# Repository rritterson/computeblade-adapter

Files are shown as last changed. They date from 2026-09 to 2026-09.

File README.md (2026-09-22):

# Compute Blade ↔ DDA GPS/RTC adapter — parallel-DDA revision

This repository contains a passive two-connector KiCad adapter that remaps the Dark Dragons Astronomy GPS PPS signal while keeping the unmodified DDA PCB parallel to the Compute Blade PCB. Physical connector pin numbers are authoritative; GPIO names are descriptions and are never interpreted as BCM pin numbers.

The project targets **KiCad 10.0.5** through the pinned `kicad/kicad:10.0.5-full` CI image.

> Passing connectivity, ERC, DRC, CAD collision, and clearance checks is required but does not make this design fabrication-ready. Connector seating forces and final BladeRunner fit still require a physical prototype.

## Approved architecture

- **J1:** Samtec `HLE-105-02-L-DV-PE-BE`, 2×5, 2.54 mm, bottom-entry/pass-through receptacle.
- **J2:** Samtec `MTLW-106-05-G-D-140`, 2×6, 2.54 mm, conventionally mounted vertical male header; its manufacturer-designated gold-plated mating post points toward the DDA.
- Adapter: 2-layer 1.0 mm FR-4, nominal 1 oz / 35 µm copper.
- Compute Blade, adapter, and DDA PCB planes are all XY.
- DDA socket/battery face points inward (−Z), toward the adapter and Compute Blade.
- DDA GNSS face points outward (+Z), toward the neighboring blade.
- The DDA remains electrically and mechanically unmodified.

The exact footprints are project-local in `pcb/Adapter.pretty/`. They use the manufacturer 2.54 mm patterns, explicit fab outlines, courtyards, 1.0 mm drills, and 1.8 mm pads. That gives a nominal 0.40 mm annular ring. The 1.0 mm board provides a conventional, stiff interposer, but the selected fabricator must still confirm 1.0 mm FR-4, 1.0 mm plated drills, and its finished-hole/annular-ring rules before ordering.

The generated connector STEP models are manufacturer-dimensioned approximations because exact configured Samtec CAD is not available to deterministic unauthenticated CI. They are not substitutes for a first-article fit test.

## Coordinate and orientation contract

```text
X = Compute Blade long axis
Y = Compute Blade width
Z = outward normal from the Compute Blade PCB

Compute Blade PCB plane = XY
adapter PCB plane       = XY
DDA PCB plane           = XY
DDA PCB normal          = +Z
DDA socket mating axis  = -Z toward adapter
J2 mating posts         = +Z
J2 six-position axis    = +X
J2 row 1 → row 2        = -Y
```

The shared DDA transform is the identity basis:

```text
[[1, 0, 0],
 [0, 1, 0],
 [0, 0, 1]]
```

`scripts/design_config.py` is the sole parameter source used by the PCB generator, geometry validator, STEP generator, SVG generator, and PNG renderer. Unit tests hard-fail if the DDA becomes upright, the GNSS face points inward, the mating direction reverses, or J2’s columns/rows change axes.

## Exact physical-pin mapping

| Physical pin | J1 Compute Blade | J2 DDA | Adapter net |
|---:|---|---|---|
| 1 | 3V3 | 3V3 | `3V3` |
| 2 | 5V | unused by DDA | `5V_PIN2` |
| 3 | GPIO2 / SDA | SDA | `SDA_GPIO2` |
| 4 | 5V | unused by DDA | `5V_PIN4` |
| 5 | GPIO3 / SCL | SCL | `SCL_GPIO3` |
| 6 | GND | GND | `GND_PIN6` |
| 7 | GPIO4 / PPS_IN | unused DDA position | `PPS_GPIO4` |
| 8 | GPIO14 / UART_TX | GPS_RX | `UART_TX_TO_GPS_RX` |
| 9 | GND | unused by DDA | `GND_PIN9` |
| 10 | GPIO15 / UART_RX | GPS_TX | `UART_RX_FROM_GPS_TX` |
| 11 | — | RTC_INT | **NC** |
| 12 | — | GPS_PPS | `PPS_GPIO4` |

Pins J1.1–J1.10 map one-for-one to J2.1–J2.10. J2.12 additionally joins J1.7/J2.7, so GPS PPS reaches Compute Blade physical pin 7 / GPIO4. J2.11 remains explicitly unconnected. Duplicate rails remain separate: `5V_PIN2`, `5V_PIN4`, `GND_PIN6`, and `GND_PIN9` are not merged by the adapter.

## Dimension provenance and stack calculation

Physically measured Compute Blade dimensions:

- PCB surface to header-plastic top: 2.500 mm.
- PCB surface to pin tip: 9.000 mm.
- Exposed post: 6.500 mm.

Manufacturer HLE requirements:

- Bottom-entry minimum reach: 2.590 mm plus host PCB thickness and the intentional seating gap.
- `J1_SEATING_GAP_MM = 0.350` is the single authoritative gap between the Compute Blade header-plastic top and adapter/J1 seating plane.
- With a 1.000 mm adapter and the 0.350 mm gap, required reach is 3.940 mm.
- The measured 6.500 mm post exceeds this requirement by 2.560 mm.
- `-PE-BE` is open/pass-through, so excess post does not bottom in a closed socket.
- Adapter underside is therefore 2.850 mm above the Compute Blade PCB. The 0.350 mm separation is an intentional assembly datum, not an assumed connector-body height; assembly should use a 0.35 mm seating gauge/fixture and verify the resulting separation on the first article.

The same exact connector Z-chain was evaluated at all requested gaps:

| Seating gap | Adapter underside | J1 required reach | J1 surplus | J2 tail clearance | Outward stack | Physical clearance | Margin after reserve |
|---:|---:|---:|---:|---:|---:|---:|---:|
| 0.300 mm | 2.800 mm | 3.890 mm | 2.610 mm | 0.366 mm | 17.776 mm | 2.1557 mm | 1.1557 mm |
| **0.350 mm** | **2.850 mm** | **3.940 mm** | **2.560 mm** | **0.416 mm** | **17.826 mm** | **2.1057 mm** | **1.1057 mm** |
| 0.400 mm | 2.900 mm | 3.990 mm | 2.510 mm | 0.466 mm | 17.876 mm | 2.0557 mm | 1.0557 mm |

The preferred 0.350 mm value passes every hard gate while retaining more BladeRunner margin than 0.400 mm and giving more tail clearance than 0.300 mm.

Manufacturer MTLW geometry:

```text
OAL                                      8.510 mm
insulator                                1.520 mm
designated -140 mating post              3.556 mm
solder tail                              3.434 mm
DDA insertion                            3.400 mm
free post after insertion                0.156 mm
lower solder-tail tip above blade PCB    0.416 mm
```

`MTLW-106-05-G-D-140` uses the normal manufacturer orientation: the `-140` post is the DDA mating end and receives the specified 10 µin gold plating; the opposite 3.434 mm segment is the solder tail. Samtec lists this exact configuration in its Reserve program. See the [exact Samtec product page](https://www.samtec.com/products/mtlw-106-05-g-d-140) and [official MTLW series print](https://suddendocs.samtec.com/catalog_english/mtlw_th.pdf).

Measured DDA geometry:

- PCB: 16.5 × 22.5 × **1.6 mm**.
- Socket mating face to socket-side PCB surface: 8.3 mm.
- Socket-side PCB surface to GNSS top: **4.0 mm total**.
- GNSS projection beyond the opposite PCB surface: 2.4 mm.
- Battery/RTC inward local envelope: 4.75 mm.

The 4.0 mm value already includes the 1.6 mm PCB. It must not be calculated as `1.6 + 4.0`.

```text
adapter underside                                  2.850 mm
+ adapter PCB                                      1.000 mm
+ MTLW insulator                                   1.520 mm
+ unused designated post after insertion           0.156 mm
= DDA socket mating face                           5.526 mm
+ mating face to socket-side PCB surface           8.300 mm
+ socket-side surface to GNSS top                  4.000 mm
= total outward stack                             17.826 mm
```

## Placement and BladeRunner clearance

The official Compute Blade STEP anchors J3 at `(133.075077, 18.325065, 0.0)` mm. The selected complete DDA projection is:

```text
X = 160.000 .. 176.500 mm
Y =  19.500 ..  42.000 mm
```

The validator extracts the official PCB solid bounds from the STEP and requires the full DDA PCB, socket, GNSS envelope, and inward battery envelope to remain inside its XY footprint with a 0.5 mm configured margin.

BladeRunner clearance uses the physical slit-edge result, not slit centerline pitch:

```text
physical per-blade clearance       19.9317 mm
safety reserve                      1.0000 mm
design maximum                     18.9317 mm
approved outward stack             17.8260 mm
physical nominal clearance          2.1057 mm
margin after 1.0 mm reserve         1.1057 mm
```

CI authenticates the pinned official `half body.stl`, rechecks its mesh encoding, triangle count, hash, and outer bounds, and applies the previously slit-edge-derived 19.9317 mm physical clearance. It does not substitute the obsolete `(-1.5, 45.0)` clearance box or the former 36 mm total-depth rule.

## Official CAD and mechanical validation

`scripts/fetch_reference_cad.py` authenticates upstream CAD at immutable Compute Blade commit `9c7e472f4fb5c74401d17cdc7a766254d78a32c6`:

- `models/blade/v1.0-mk4/v1.0_mk4_DEV.step`
- `models/bladerunner/19-inch/half body.stl`
- `models/bladerunner/19-inch/left bracket.stl`
- `models/bladerunner/19-inch/right bracket.stl`

Pure-Python validation checks the shared transforms, pin-1 mapping, designated J2 mating end, connector reach, 3.40 mm insertion, the 0.30 mm minimum tail clearance, DDA XY keep-in, 17.826 mm stack, 2.00 mm minimum physical clearance, and 1.00 mm minimum post-reserve margin. The CadQuery assembly stage additionally intersects the DDA, J2, and adapter-outside-J1 region against the exact official Compute Blade B-Rep and fails on material overlap.

The confirmed DDA pin-1 orientation remains:

- readable GNSS/component side: bottom-left;
- underside/socket-hole view: bottom-right.

This is encoded independently of electrical net names.

## Inspecting the assembly

`scripts/generate_assembly_model.py` produces:

- `mechanical/generated/full_assembly.step`
- `mechanical/generated/full_assembly_lightweight.step`
- `mechanical/generated/full_assembly_with_bladerunner.step`
- standalone J1/J2 approximation STEP models
- top, side, end, isometric, J1-closeup, and J2/DDA-closeup PNGs

The full assembly imports the exact official Compute Blade B-Rep. The BladeRunner-context assembly adds the validated 18.9317 mm design plane and 19.9317 mm physical-clearance plane. All placement uses the same boxes and transforms as `validate_geometry.py`; there is no separate visual-only placement.

Open the STEP files in FreeCAD. From a successful GitHub Actions run, download the `compute-blade-dda-adapter-reports` artifact for the STEP files, fixed renders, manifests, ERC/DRC reports, and board views. The visual model is an inspection aid and does not replace a physical prototype.

## Regeneration and CI

```sh
python3 scripts/fetch_reference_cad.py
python3 scripts/generate_schematic.py
python3 scripts/generate_or_update_pcb.py
python3 scripts/generate_mechanical_model.py
python3 scripts/verify_connectivity.py
python3 -m unittest discover -s scripts -p 'test_*.py' -v
python3 scripts/validate_geometry.py
python3 -m pip install --requirement requirements-assembly.txt
python3 scripts/generate_assembly_model.py
```

GitHub Actions repeats deterministic generation, connectivity verification, unit tests, geometry validation, STEP round-trip checks, blank-render checks, KiCad ERC/DRC, Gerber export, and Excellon drill export. Download `compute-blade-dda-adapter-manufacturing` for `compute-blade-dda-adapter-gerbers.zip`; the BOM is included in `compute-blade-dda-adapter-reports`.

## Prototype-only risks

- First-article confirmation that the specified 0.350 mm HLE seating gap can be set and retained using the assembly gauge/fixture, plus practical soldering on 1.0 mm FR-4.
- Production-tolerance and solder-fillet confirmation for the nominal 0.416 mm gap between the J2 tail tips and Compute Blade PCB plane.
- Physical connector insertion and extraction forces.
- Residual differences between simplified connector bodies and production parts.
- Final assembled fit in a real 19-inch BladeRunner, including manufacturing and seating tolerances.
- First-article confirmation before ordering multiple boards.

The project must not be described as fabrication-ready until those physical checks are closed.

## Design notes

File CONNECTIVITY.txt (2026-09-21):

Compute Blade to DDA GPS/RTC adapter connectivity
Physical header pin numbers only

Pin     Net
------- ---------------------------
J1.1   3V3
J1.2   5V_PIN2
J1.3   SDA_GPIO2
J1.4   5V_PIN4
J1.5   SCL_GPIO3
J1.6   GND_PIN6
J1.7   PPS_GPIO4
J1.8   UART_TX_TO_GPS_RX
J1.9   GND_PIN9
J1.10  UART_RX_FROM_GPS_TX
J2.1   3V3
J2.2   5V_PIN2
J2.3   SDA_GPIO2
J2.4   5V_PIN4
J2.5   SCL_GPIO3
J2.6   GND_PIN6
J2.7   PPS_GPIO4
J2.8   UART_TX_TO_GPS_RX
J2.9   GND_PIN9
J2.10  UART_RX_FROM_GPS_TX
J2.11  NC
J2.12  PPS_GPIO4

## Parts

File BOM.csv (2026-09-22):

Reference | Quantity | Manufacturer | Manufacturer Part Number | Description | Mounting
J1 | 1 | Samtec | HLE-105-02-L-DV-PE-BE | 2x5 2.54 mm bottom-entry pass-through receptacle | Top / through-hole
J2 | 1 | Samtec | MTLW-106-05-G-D-140 | 2x6 2.54 mm variable-post header in conventional mating orientation | Top / through-hole

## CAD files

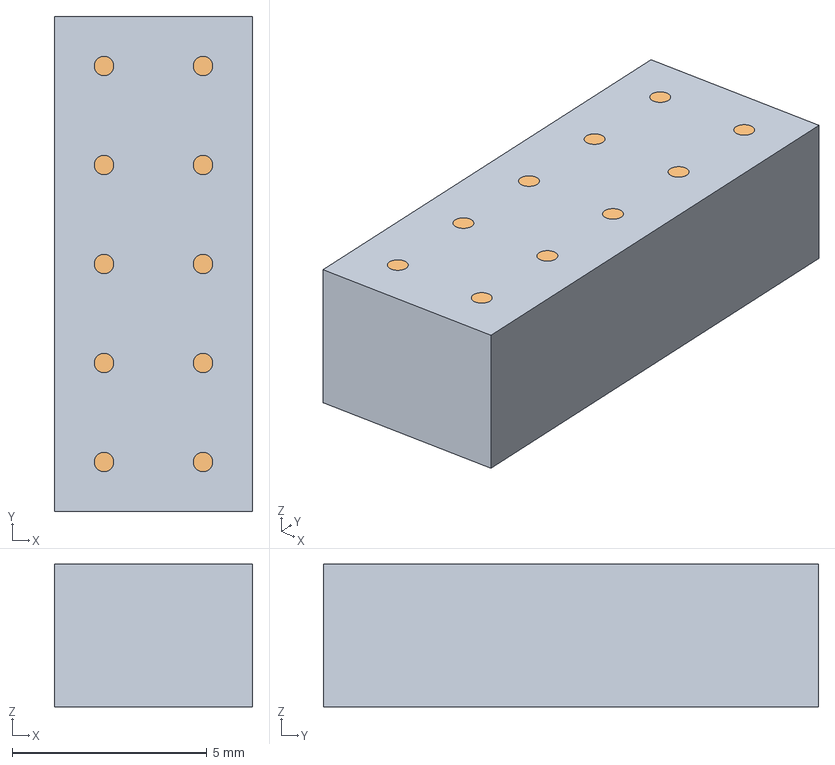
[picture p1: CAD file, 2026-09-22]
mechanical/generated/j1_hle_105_02_l_dv_pe_be.step
5.08 x 12.7 x 3.66 mm

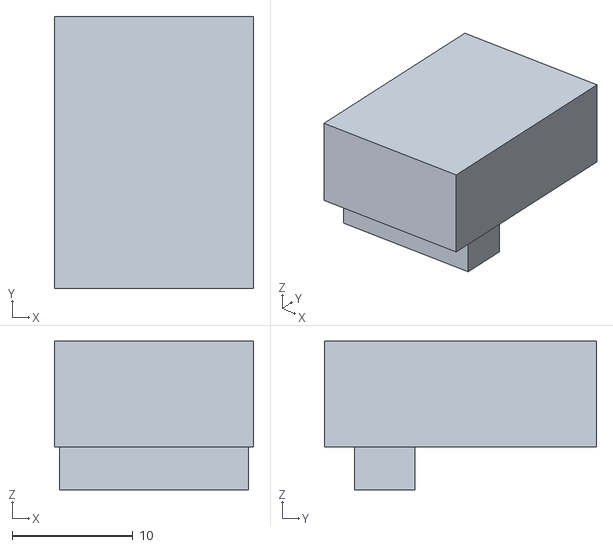
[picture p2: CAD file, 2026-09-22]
mechanical/generated/dda_simple_default.stl
16.5 x 22.5 x 12.3

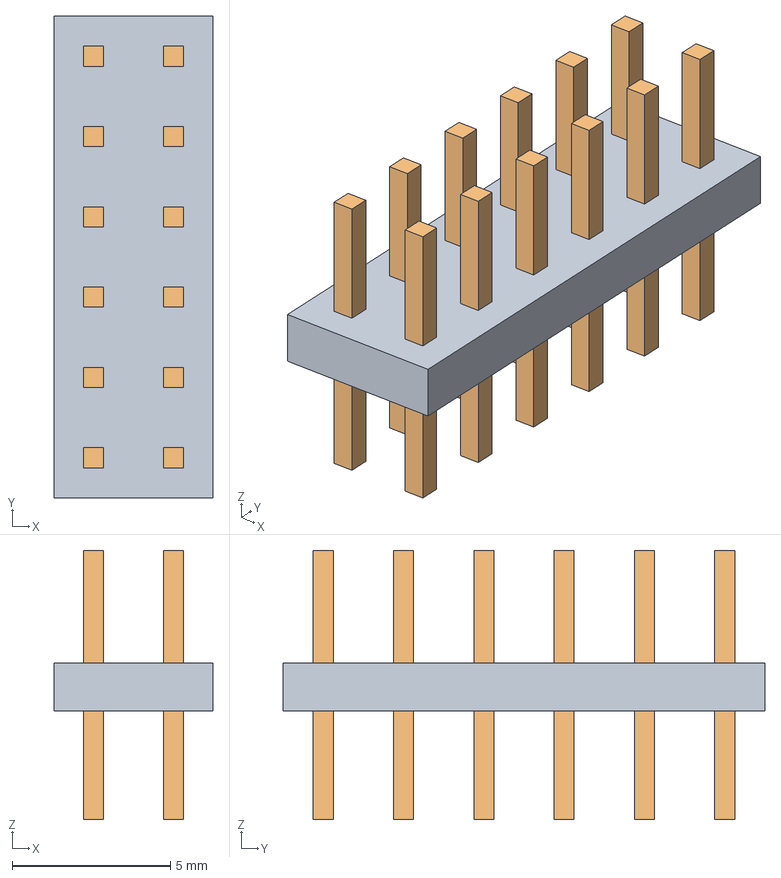
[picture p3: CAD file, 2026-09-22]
mechanical/generated/j2_mtlw_106_05_g_d_140.step
5.03 x 15.2 x 8.51 mm

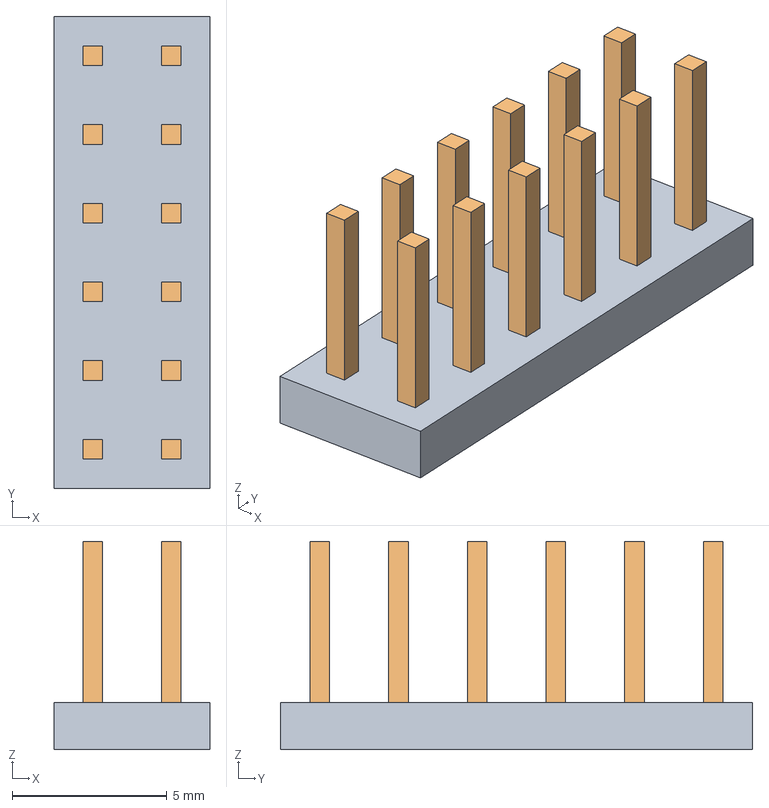
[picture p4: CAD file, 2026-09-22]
mechanical/generated/j2_mtlw_106_06_g_d_035_reverse.step
5.03 x 15.2 x 6.73 mm

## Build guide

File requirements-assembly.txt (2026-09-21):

# Pinned CAD and headless-rendering toolchain used by pcb-ci.yml.
cadquery==2.5.2
cadquery-ocp==7.7.2
numpy==2.0.2
Pillow==11.3.0

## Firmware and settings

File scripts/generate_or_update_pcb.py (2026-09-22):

#!/usr/bin/env python3
"""Deterministically generate the routed two-connector KiCad PCB."""

from __future__ import annotations

import uuid
import math
import heapq
from pathlib import Path

from design_config import (
    BOARD_THICKNESS_MM,
    BOARD_BOUNDS_RELATIVE_J1_MM,
    ROUTING_BOUNDS_RELATIVE_J1_MM,
    J1_FOOTPRINT,
    J1_MODEL,
    J1_ORIGIN_MM,
    J1_CANDIDATE_PART,
    J2_FOOTPRINT,
    J2_FOOTPRINT_ROTATION_DEG,
    J2_MODEL,
    J2_ORIGIN_MM,
    J2_CANDIDATE_PART,
    J2_CENTERLINE_OFFSET_MM,
    PITCH_MM,
    POWER_TRACE_WIDTH_MM,
    SIGNAL_TRACE_WIDTH_MM,
)


ROOT = Path(__file__).resolve().parents[1]
BOARD_PATH = ROOT / "pcb" / "compute-blade-dda-adapter.kicad_pcb"
REPORT_PATH = ROOT / "CONNECTIVITY.txt"
BOM_PATH = ROOT / "BOM.csv"
UUID_NAMESPACE = uuid.UUID("5ec70a29-b9c1-44f3-96f8-6bd81180ce3d")

NET_BY_PIN = {
    1: "3V3", 2: "5V_PIN2", 3: "SDA_GPIO2", 4: "5V_PIN4",
    5: "SCL_GPIO3", 6: "GND_PIN6", 7: "PPS_GPIO4",
    8: "UART_TX_TO_GPS_RX", 9: "GND_PIN9", 10: "UART_RX_FROM_GPS_TX",
}
NET_CODE = {net: index for index, net in enumerate(NET_BY_PIN.values(), start=1)}
POWER_NETS = {"3V3", "5V_PIN2", "5V_PIN4", "GND_PIN6", "GND_PIN9"}
ROUTE_ORDER = (1, 2, 5, 8, 3, 4, 6, 7, 9, 10)


def uid(name: str) -> str:
    return str(uuid.uuid5(UUID_NAMESPACE, name))


def fmt(value: float) -> str:
    return f"{value:.3f}".rstrip("0").rstrip(".")


def local_pad(ref: str, pin: int) -> tuple[float, float]:
    row = (pin - 1) // 2
    x = (0.0 if pin % 2 else -PITCH_MM) if ref == "J1" else (0.0 if pin % 2 else PITCH_MM)
    return x, row * PITCH_MM


def global_pad(ref: str, pin: int) -> tuple[float, float]:
    lx, ly = local_pad(ref, pin)
    ox, oy = J1_ORIGIN_MM if ref == "J1" else J2_ORIGIN_MM
    angle = 0.0 if ref == "J1" else J2_FOOTPRINT_ROTATION_DEG
    radians = math.radians(angle)
    # KiCad board coordinates are Y-down, so positive footprint rotation uses
    # the inverse sign of the conventional Cartesian XY matrix.
    return (
        ox + math.cos(radians) * lx + math.sin(radians) * ly,
        oy - math.sin(radians) * lx + math.cos(radians) * ly,
    )


def net_for(ref: str, pin: int) -> str | None:
    if ref == "J2" and pin == 11:
        return None
    if ref == "J2" and pin == 12:
        return NET_BY_PIN[7]
    return NET_BY_PIN[pin]


def pad(ref: str, pin: int) -> str:
    x, y = local_pad(ref, pin)
    net = net_for(ref, pin)
    net_clause = "" if net is None else f' (net {NET_CODE[net]} "{net}")'
    shape = "rect" if pin == 1 else "circle"
    return f'''    (pad "{pin}" thru_hole {shape} (at {fmt(x)} {fmt(y)})
      (size 1.8 1.8) (drill 1) (layers "*.Cu" "*.Mask"){net_clause}
      (uuid {uid(f'{ref}-pad-{pin}')}))'''


def fp_line(ref: str, index: int, start: tuple[float, float], end: tuple[float, float],
            layer: str, width: float) -> str:
    return f'''    (fp_line (start {fmt(start[0])} {fmt(start[1])}) (end {fmt(end[0])} {fmt(end[1])})
      (stroke (width {fmt(width)}) (type solid)) (layer "{layer}")
      (uuid {uid(f'{ref}-line-{index}-{layer}')}))'''


def fp_rect(ref: str, index: int, start: tuple[float, float], end: tuple[float, float],
            layer: str, width: float) -> str:
    return f'''    (fp_rect (start {fmt(start[0])} {fmt(start[1])}) (end {fmt(end[0])} {fmt(end[1])})
      (stroke (width {fmt(width)}) (type solid)) (fill none) (layer "{layer}")
      (uuid {uid(f'{ref}-rect-{index}-{layer}')}))'''


def j1_footprint() -> str:
    outline = []
    # Samtec HLE five-position double-row body and courtyard.
    for layer, width, bounds in (
        ("F.SilkS", 0.12, (-3.87, -1.33, 1.33, 11.49)),
        ("F.Fab", 0.10, (-3.81, -1.27, 1.27, 11.43)),
        ("F.CrtYd", 0.05, (-4.31, -1.77, 1.77, 11.93)),
    ):
        x0, y0, x1, y1 = bounds
        outline.append(fp_rect("J1", len(outline), (x0, y0), (x1, y1), layer, width))
    pads = "\n".join(pad("J1", pin) for pin in range(1, 11))
    return f'''  (footprint "{J1_FOOTPRINT}"
    (layer "F.Cu")
    (uuid {uid('J1-footprint')})
    (at {fmt(J1_ORIGIN_MM[0])} {fmt(J1_ORIGIN_MM[1])})
    (descr "Samtec HLE-105-02-L-DV-PE-BE 2x5 bottom-entry pass-through socket")
    (tags "Samtec HLE bottom entry pass through 2x5 2.54mm")
    (property "Reference" "J1" (at -1.27 13.0 0) (layer "F.SilkS")
      (uuid {uid('J1-reference')}) (effects (font (size 1 1) (thickness 0.15))))
    (property "Value" "HLE-105-02-L-DV-PE-BE" (at -1.27 13.0 0) (layer "F.Fab")
      (uuid {uid('J1-value')}) (effects (font (size 1 1) (thickness 0.15))))
    (attr through_hole)
{chr(10).join(outline)}
    (fp_text user "1" (at 2 -0.8 0) (layer "F.SilkS")
      (uuid {uid('J1-pin1-text')}) (effects (font (size 0.8 0.8) (thickness 0.14))))
{pads}
    (model "{J1_MODEL}" (offset (xyz 0 0 0)) (scale (xyz 1 1 1)) (rotate (xyz 0 0 0)))
  )'''


def j2_footprint() -> str:
    graphics = [
        fp_rect("J2", 0, (-1.745, -1.77), (4.285, 14.47), "F.CrtYd", 0.05),
        fp_rect("J2", 1, (-1.305, -1.33), (3.845, 14.03), "F.SilkS", 0.12),
        fp_rect("J2", 2, (-1.245, -1.27), (3.785, 13.97), "F.Fab", 0.10),
        fp_line("J2", 3, (-1.245, -1.27), (0.0, -1.27), "F.SilkS", 0.12),
        fp_line("J2", 4, (-1.245, -1.27), (-1.245, 0.0), "F.SilkS", 0.12),
    ]
    pads = "\n".join(pad("J2", pin) for pin in range(1, 13))
    return f'''  (footprint "{J2_FOOTPRINT}"
    (layer "F.Cu")
    (uuid {uid('J2-footprint')})
    (at {fmt(J2_ORIGIN_MM[0])} {fmt(J2_ORIGIN_MM[1])} {fmt(J2_FOOTPRINT_ROTATION_DEG)})
    (descr "Samtec MTLW-106-05-G-D-140 conventional 2x6 vertical header")
    (tags "Samtec MTLW conventional vertical 2x6 2.54mm")
    (property "Reference" "J2" (at 1.27 15.2 0) (layer "F.SilkS")
      (uuid {uid('J2-reference')}) (effects (font (size 1 1) (thickness 0.15))))
    (property "Value" "MTLW-106-05-G-D-140" (at 1.27 15.2 0) (layer "F.Fab")
      (uuid {uid('J2-value')}) (effects (font (size 1 1) (thickness 0.15))))
    (attr through_hole)
{chr(10).join(graphics)}
    (fp_text user "1" (at -2.4 0 0) (layer "F.SilkS")
      (uuid {uid('J2-pin1-text')}) (effects (font (size 0.8 0.8) (thickness 0.14))))
    (fp_text user "DDA MATING END +Z" (at 1.27 6.35 90) (layer "F.SilkS")
      (uuid {uid('J2-mating-direction')}) (effects (font (size 0.8 0.8) (thickness 0.12))))
{pads}
    (model "{J2_MODEL}" (offset (xyz 0 0 0)) (scale (xyz 1 1 1)) (rotate (xyz 0 0 0)))
  )'''


def segment(start: tuple[float, float], end: tuple[float, float], layer: str,
            net: str, key: str) -> str:
    width = POWER_TRACE_WIDTH_MM if net in POWER_NETS else SIGNAL_TRACE_WIDTH_MM
    return (
        f'  (segment (start {fmt(start[0])} {fmt(start[1])}) '
        f'(end {fmt(end[0])} {fmt(end[1])}) (width {fmt(width)}) '
        f'(layer "{layer}") (net {NET_CODE[net]}) (uuid {uid(key)}))'
    )


def distance_to_segment(point: tuple[float, float], start: tuple[float, float],
                        end: tuple[float, float]) -> float:
    vx, vy = end[0] - start[0], end[1] - start[1]
    length2 = vx * vx + vy * vy
    if length2 == 0:
        return math.dist(point, start)
    t = max(0.0, min(1.0, ((point[0] - start[0]) * vx + (point[1] - start[1]) * vy) / length2))
    return math.dist(point, (start[0] + t * vx, start[1] + t * vy))


def distance_between_segments(
    a: tuple[float, float], b: tuple[float, float],
    c: tuple[float, float], d: tuple[float, float],
) -> float:
    """Return the exact minimum distance between two closed 2-D segments."""
    def orientation(p, q, r):
        return (q[0] - p[0]) * (r[1] - p[1]) - (q[1] - p[1]) * (r[0] - p[0])

    def on_segment(p, q, r):
        return (
            min(p[0], r[0]) - 1e-9 <= q[0] <= max(p[0], r[0]) + 1e-9
            and min(p[1], r[1]) - 1e-9 <= q[1] <= max(p[1], r[1]) + 1e-9
        )

    ab_c, ab_d = orientation(a, b, c), orientation(a, b, d)
    cd_a, cd_b = orientation(c, d, a), orientation(c, d, b)
    if ab_c * ab_d < 0 and cd_a * cd_b < 0:
        return 0.0
    if (
        (abs(ab_c) <= 1e-9 and on_segment(a, c, b))
        or (abs(ab_d) <= 1e-9 and on_segment(a, d, b))
        or (abs(cd_a) <= 1e-9 and on_segment(c, a, d))
        or (abs(cd_b) <= 1e-9 and on_segment(c, b, d))
    ):
        return 0.0
    return min(
        distance_to_segment(a, c, d), distance_to_segment(b, c, d),
        distance_to_segment(c, a, b), distance_to_segment(d, a, b),
    )


def segment_intersects_aabb(
    start: tuple[float, float], end: tuple[float, float],
    xmin: float, xmax: float, ymin: float, ymax: float,
) -> bool:
    """Liang-Barsky test for a segment intersecting a closed rectangle."""
    dx, dy = end[0] - start[0], end[1] - start[1]
    lower, upper = 0.0, 1.0
    for p, q in (
        (-dx, start[0] - xmin), (dx, xmax - start[0]),
        (-dy, start[1] - ymin), (dy, ymax - start[1]),
    ):
        if abs(p) <= 1e-12:
            if q < 0:
                return False
            continue
        ratio = q / p
        if p < 0:
            lower = max(lower, ratio)
        else:
            upper = min(upper, ratio)
        if lower > upper:
            return False
    return True


def segment_violates_pad_clearance(
    start: tuple[float, float], end: tuple[float, float],
    center: tuple[float, float], pin: int, track_width: float,
) -> bool:
    clearance = track_width / 2 + 0.15
    if pin == 1:
        # Pin 1 is a 1.8 mm square pad; treating it as a 0.9 mm-radius circle
        # misses copper near its corners.
        half_extent = 0.90 + clearance
        return segment_intersects_aabb(
            start, end,
            center[0] - half_extent, center[0] + half_extent,
            center[1] - half_extent, center[1] + half_extent,
        )
    return distance_to_segment(center, start, end) < 0.90 + clearance


def simplify(points: list[tuple[float, float]]) -> list[tuple[float, float]]:
    result = []
    for point in points:
        if result and math.dist(result[-1], point) < 1e-6:
            continue
        result.append(point)
        while len(result) >= 3:
            a, b, c = result[-3:]
            cross = (b[0] - a[0]) * (c[1] - b[1]) - (b[1] - a[1]) * (c[0] - b[0])
            # Collapse only forward collinear points.  A pad escape followed
            # by a grid path that briefly doubles back is intentional; using
            # the cross product alone deleted that escape and let the first
            # trace segment graze the neighboring connector pad.
            dot = (b[0] - a[0]) * (c[0] - b[0]) + (b[1] - a[1]) * (c[1] - b[1])
            if abs(cross) > 1e-8 or dot <= 0:
                break
            result.pop(-2)
    return result


def pad_escape(ref: str, pin: int) -> tuple[float, float]:
    """Give every THT pad a straight 1.5 mm exit away from its paired pad."""
    x, y = global_pad(ref, pin)
    if ref == "J1":
        return x + (1.5 if pin % 2 else -1.5), y
    return x, y + (1.5 if pin % 2 else -1.5)


def routed_points(start: tuple[float, float], start_escape: tuple[float, float],
                  end_escape: tuple[float, float], end: tuple[float, float], layer: str,
                  net: str, completed: list[tuple[str, str, float, list[tuple[float, float]]]]) -> list[tuple[float, float]]:
    """Deterministically find a clearance-aware 0.1 mm grid route."""
    bounds = ROUTING_BOUNDS_RELATIVE_J1_MM
    xmin = J1_ORIGIN_MM[0] + bounds[0] + 0.5
    xmax = J1_ORIGIN_MM[0] + bounds[1] - 0.5
    ymin = J1_ORIGIN_MM[1] + bounds[2] + 0.5
    ymax = J1_ORIGIN_MM[1] + bounds[3] - 0.5
    step = 0.25
    width = POWER_TRACE_WIDTH_MM if net in POWER_NETS else SIGNAL_TRACE_WIDTH_MM
    start_cell = (round((start_escape[0] - xmin) / step), round((start_escape[1] - ymin) / step))
    end_cell = (round((end_escape[0] - xmin) / step), round((end_escape[1] - ymin) / step))
    pad_centers = [
        (global_pad(ref, pin), net_for(ref, pin), pin)
        for ref, count in (("J1", 10), ("J2", 12))
        for pin in range(1, count + 1)
    ]

    def position(cell: tuple[int, int]) -> tuple[float, float]:
        return xmin + cell[0] * step, ymin + cell[1] * step

    def segment_blocked(a: tuple[float, float], b: tuple[float, float]) -> bool:
        if any(point[0] < xmin or point[0] > xmax or point[1] < ymin or point[1] > ymax for point in (a, b)):
            return True
        for center, pad_net, pin in pad_centers:
            if pad_net != net and segment_violates_pad_clearance(a, b, center, pin, width):
                return True
        for track_layer, track_net, track_width, points in completed:
            if track_layer != layer or track_net == net:
                continue
            clearance = (width + track_width) / 2 + 0.15
            probes = (a, ((a[0] + b[0]) / 2, (a[1] + b[1]) / 2), b)
            if any(
                distance_to_segment(probe, points[index], points[index + 1]) < clearance
                for probe in probes
                for index in range(len(points) - 1)
            ):
                return True
        return False

    # The two pad-escape segments are not A* edges, so validate them explicitly.
    if segment_blocked(start, start_escape) or segment_blocked(end_escape, end):
        raise RuntimeError(f"pad escape for {net} on {layer} violates clearance")

    queue = [(0.0, 0.0, start_cell)]
    previous: dict[tuple[int, int], tuple[int, int] | None] = {start_cell: None}
    cost = {start_cell: 0.0}
    directions = ((1, 0), (0, -1), (-1, 0), (0, 1), (1, -1), (-1, -1), (-1, 1), (1, 1))
    while queue:
        _estimate, current_cost, current = heapq.heappop(queue)
        if current == end_cell:
            break
        if current_cost != cost.get(current):
            continue
        for dx, dy in directions:
            neighbor = current[0] + dx, current[1] + dy
            if segment_blocked(position(current), position(neighbor)):
                continue
            move = math.sqrt(2.0) if dx and dy else 1.0
            candidate = current_cost + move
            if candidate >= cost.get(neighbor, float("inf")):
                continue
            cost[neighbor] = candidate
            previous[neighbor] = current
            heuristic = math.hypot(end_cell[0] - neighbor[0], end_cell[1] - neighbor[1])
            heapq.heappush(queue, (candidate + heuristic, candidate, neighbor))
    if end_cell not in previous:
        raise RuntimeError(f"could not route {net} on {layer} with configured clearances")
    cells = []
    current: tuple[int, int] | None = end_cell
    while current is not None:
        cells.append(current)
        current = previous[current]
    points = [start, start_escape, *(position(cell) for cell in reversed(cells)), end_escape, end]
    return simplify(points)


def via_clear(
    point: tuple[float, float], net: str,
    completed: list[tuple[str, str, float, list[tuple[float, float]]]],
) -> bool:
    for ref, count in (("J1", 10), ("J2", 12)):
        for pin in range(1, count + 1):
            if net_for(ref, pin) != net and math.dist(point, global_pad(ref, pin)) < 1.15:
                return False
    for _layer, track_net, width, points in completed:
        if track_net == net:
            continue
        clearance = 0.4 + width / 2 + 0.15
        if any(distance_to_segment(point, points[i], points[i + 1]) < clearance for i in range(len(points) - 1)):
            return False
    return True


def route_connection(
    start: tuple[float, float], start_escape: tuple[float, float],
    end_escape: tuple[float, float], end: tuple[float, float],
    preferred: str, net: str,
    completed: list[tuple[str, str, float, list[tuple[float, float]]]],
) -> tuple[
    list[tuple[str, list[tuple[float, float]]]],
    tuple[float, float] | tuple[tuple[float, float], tuple[float, float]] | None,
]:
    other = "B.Cu" if preferred == "F.Cu" else "F.Cu"
    for layer in (preferred, other):
        try:
            return [(layer, routed_points(start, start_escape, end_escape, end, layer, net, completed))], None
        except RuntimeError:
            pass
    # A single plated through via is sufficient for the only topological
    # crossings created by rotating the destination connector 90 degrees.
    for first, second in ((preferred, other), (other, preferred)):
        for x in (104.0, 108.0, 112.0, 116.0, 120.0, 124.0):
            for y in (51.0, 54.0, 57.0, 60.0, 63.0, 66.0, 69.0, 72.0, 75.0, 78.0):
                via = (x, y)
                if not via_clear(via, net, completed):
                    continue
                try:
                    first_points = routed_points(
                        start, start_escape, via, via, first, net, completed
                    )
                    second_points = routed_points(
                        via, via, end_escape, end, second, net, completed
                    )
                    return [(first, first_points), (second, second_points)], via
                except RuntimeError:
                    continue
    # Final deterministic fallback: two vias put the long middle span on the
    # opposite layer while keeping both connector escapes on their preferred
    # layer. This handles the 90-degree fan-out without adding more layers.
    for outer, middle in ((preferred, other), (other, preferred)):
        for y1 in (51.0, 55.0, 59.0, 63.0, 67.0, 71.0, 75.0, 79.0):
            via1 = (106.0, y1)
            if not via_clear(via1, net, completed):
                continue
            for y2 in (51.0, 55.0, 59.0, 63.0, 67.0, 71.0, 75.0, 79.0):
                via2 = (122.0, y2)
                if not via_clear(via2, net, completed):
                    continue
                try:
                    first_points = routed_points(start, start_escape, via1, via1, outer, net, completed)
                    middle_points = routed_points(via1, via1, via2, via2, middle, net, completed)
                    last_points = routed_points(via2, via2, end_escape, end, outer, net, completed)
                    return [
                        (outer, first_points), (middle, middle_points), (outer, last_points)
                    ], (via1, via2)
                except RuntimeError:
                    continue
    raise RuntimeError(f"could not route {net} with up to two vias")


def via(point: tuple[float, float], net: str, key: str) -> str:
    return (
        f'  (via (at {fmt(point[0])} {fmt(point[1])}) (size 0.8) (drill 0.4) '
        f'(layers "F.Cu" "B.Cu") (net {NET_CODE[net]}) (uuid {uid(key)}))'
    )


def assert_route_clearances(
    completed: list[tuple[str, str, float, list[tuple[float, float]]]],
) -> None:
    """Independently audit every finished copper segment before serialization."""
    segments = [
        (layer, net, width, points[index], points[index + 1])
        for layer, net, width, points in completed
        for index in range(len(points) - 1)
    ]
    for layer, net, width, start, end in segments:
        for ref, count in (("J1", 10), ("J2", 12)):
            for pin in range(1, count + 1):
                if net_for(ref, pin) == net:
                    continue
                center = global_pad(ref, pin)
                if segment_violates_pad_clearance(start, end, center, pin, width):
                    raise RuntimeError(
                        f"{net} {layer} segment {start}->{end} violates copper clearance "
                        f"to {ref}.{pin} at {center}"
                    )
    for index, (layer, net, width, start, end) in enumerate(segments):
        for other_layer, other_net, other_width, other_start, other_end in segments[index + 1:]:
            if layer != other_layer or net == other_net:
                continue
            required = (width + other_width) / 2 + 0.15
            actual = distance_between_segments(start, end, other_start, other_end)
            if actual < required - 1e-6:
                raise RuntimeError(
                    f"{net}/{other_net} segments on {layer} have only {actual:.4f} mm "
                    f"centerline clearance; {required:.4f} mm required"
                )
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

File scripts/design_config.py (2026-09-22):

#!/usr/bin/env python3
"""Single authoritative electrical-placement and mechanical-stack configuration."""

from __future__ import annotations

from dataclasses import dataclass


# Assembly coordinates are those of the official Compute Blade STEP:
# X = blade long axis, Y = blade width, Z = outward PCB normal.
PITCH_MM = 2.54
BOARD_THICKNESS_MM = 1.0
SIGNAL_TRACE_WIDTH_MM = 0.25
POWER_TRACE_WIDTH_MM = 0.50

# J1 pin 1 is the official STEP J3 anchor. KiCad coordinates are translated
# into that frame by subtracting this board-space origin.
J1_ORIGIN_MM = (100.0, 60.16)

# The approved DDA placement is expressed in the official STEP frame. The
# physical pin-1 center is the leftmost column in the row farther from the DDA
# top edge: (160 + 1.90, 19.5 + 6.04) mm.
DDA_TARGET_BOUNDS_STEP_MM = (160.0, 176.5, 19.5, 42.0)
COMPUTE_BLADE_STEP_J3_ANCHOR_MM = (133.07507717394, 18.325064806914, 0.0)
J2_PIN1_STEP_MM = (
    DDA_TARGET_BOUNDS_STEP_MM[0] + 1.90,
    DDA_TARGET_BOUNDS_STEP_MM[2] + 6.04,
)
J2_ORIGIN_MM = (
    J1_ORIGIN_MM[0] + J2_PIN1_STEP_MM[0] - COMPUTE_BLADE_STEP_J3_ANCHOR_MM[0],
    J1_ORIGIN_MM[1] + J2_PIN1_STEP_MM[1] - COMPUTE_BLADE_STEP_J3_ANCHOR_MM[1],
)
J2_CENTERLINE_OFFSET_MM = J2_ORIGIN_MM[0] - J1_ORIGIN_MM[0]

# Compact interposer outline. The DDA itself overhangs this board while staying
# inside the Compute Blade footprint.
BOARD_BOUNDS_RELATIVE_J1_MM = (-5.0, 44.0, -3.0, 13.0)
# The pathfinder may explore a larger virtual field, but generated copper is
# asserted to remain inside the physical outline before the board is written.
ROUTING_BOUNDS_RELATIVE_J1_MM = (-5.0, 44.0, -10.0, 20.0)
DDA_PCB_ENVELOPE_MARGIN_MM = 0.5

# The project-local MTLW footprint uses local +Y for successive connector
# columns and local +X from odd to even pins. +90 degrees maps columns to global
# +X and the odd-to-even row vector to global -Y.
J2_FOOTPRINT_ROTATION_DEG = 90.0

# Parallel-DDA orientation contract. Local DDA X/Y/Z map directly to assembly
# X/Y/Z. The GNSS face is +Z; the socket/battery face and mating direction are
# -Z toward the adapter and Compute Blade.
DDA_COLUMN_AXIS = (1.0, 0.0, 0.0)
DDA_TOP_TO_BOTTOM_AXIS = (0.0, 1.0, 0.0)
DDA_PCB_NORMAL = (0.0, 0.0, 1.0)
DDA_SOCKET_MATING_AXIS = (0.0, 0.0, -1.0)
J2_COLUMN_AXIS = (1.0, 0.0, 0.0)
J2_ROW1_TO_ROW2_AXIS = (0.0, -1.0, 0.0)
J2_MATING_DIRECTION = (0.0, 0.0, 1.0)
J2_SOLDER_TAIL_AXIS = (0.0, 0.0, -1.0)
DDA_ASSEMBLY_BASIS = ((1.0, 0.0, 0.0), (0.0, 1.0, 0.0), (0.0, 0.0, 1.0))
DDA_ROTATION_180 = False

# Exact manufacturer part selections. Footprints are project-local,
# dimension-driven implementations of the Samtec recommended through-hole
# patterns with explicit fab/courtyard data.
J1_FOOTPRINT = "Adapter:Samtec_HLE-105-02-L-DV-PE-BE"
J2_FOOTPRINT = "Adapter:Samtec_MTLW-106-05-G-D-140"
J1_MODEL = "${KIPRJMOD}/../mechanical/generated/j1_hle_105_02_l_dv_pe_be.step"
J2_MODEL = "${KIPRJMOD}/../mechanical/generated/j2_mtlw_106_05_g_d_140.step"
J1_CANDIDATE_PART = "Samtec HLE-105-02-L-DV-PE-BE"
J2_CANDIDATE_PART = "Samtec MTLW-106-05-G-D-140"
J2_USES_DESIGNATED_MATING_END = True

# Physically measured Compute Blade extension-header dimensions.
COMPUTE_BLADE_HEADER_PLASTIC_TOP_MM = 2.5
COMPUTE_BLADE_HEADER_PIN_TIP_MM = 9.0
COMPUTE_BLADE_EXPOSED_POST_MM = 6.5

# HLE-105-02-L-DV-PE-BE manufacturer geometry. Bottom entry requires at least
# 2.59 mm of post reach plus the host-board thickness and the intentional gap
# above the Compute Blade header housing. The housing is open/pass-through, so
# the remaining Compute Blade post cannot bottom in a closed bore.
J1_SOCKET_BODY_HEIGHT_MM = 3.66
J1_BOTTOM_ENTRY_CONTACT_MIN_MM = 2.59
J1_SEATING_GAP_CANDIDATES_MM = (0.30, 0.35, 0.40)
J1_SEATING_GAP_MM = 0.35
J1_INSERTION_DEPTH_MIN_MM = (
    J1_BOTTOM_ENTRY_CONTACT_MIN_MM + BOARD_THICKNESS_MM + J1_SEATING_GAP_MM
)
J1_INSERTION_DEPTH_MAX_MM = COMPUTE_BLADE_EXPOSED_POST_MM
J1_NOMINAL_STACK_HEIGHT_MM = COMPUTE_BLADE_HEADER_PLASTIC_TOP_MM
ADAPTER_Z_ABOVE_BLADE_MM = J1_NOMINAL_STACK_HEIGHT_MM + J1_SEATING_GAP_MM
J1_BODY_Z_MIN_MM = ADAPTER_Z_ABOVE_BLADE_MM + BOARD_THICKNESS_MM
J1_BODY_Z_MAX_MM = J1_BODY_Z_MIN_MM + J1_SOCKET_BODY_HEIGHT_MM

# Conventional MTLW-106-05-G-D-140 manufacturer geometry. The -140 dimension
# is the designated, gold-plated mating post; the opposite end is the solder
# tail. The body sits conventionally on the adapter's outward/top surface.
J2_OAL_MM = 8.510
J2_BODY_HEIGHT_MM = 1.520
J2_MATING_POST_LENGTH_MM = 3.556  # -140 inches converted to millimetres
J2_SOLDER_TAIL_LENGTH_MM = J2_OAL_MM - J2_BODY_HEIGHT_MM - J2_MATING_POST_LENGTH_MM
J2_LOWER_POST_LENGTH_MM = J2_SOLDER_TAIL_LENGTH_MM
J2_MIN_SOLDER_PROTRUSION_BELOW_PCB_MM = 0.8
J2_BODY_PLAN_MM = (15.24, 5.03)

# User-defined DDA engagement requirement.
DDA_ACCEPTABLE_REMAINING_EXPOSED_POST_MM = 3.1
DDA_MIN_ACCEPTABLE_INSERTION_MM = 3.40
J2_POST_LENGTH_MARGIN_AT_MIN_INSERTION_MM = round(
    J2_MATING_POST_LENGTH_MM - DDA_MIN_ACCEPTABLE_INSERTION_MM, 3
)
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

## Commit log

2026-09-21 Create Compute Blade to DDA GPS RTC adapter project
    [compute-blade-dda-adapter.kicad_pcb, compute-blade-dda-adapter.kicad_sch]
2026-09-21 Resolve KiCad libraries in CI
    [generate_schematic.py]
2026-09-21 Fix KiCad board text syntax
    [compute-blade-dda-adapter.kicad_pcb]
2026-09-21 Correct bottom connector routing geometry
    [compute-blade-dda-adapter.kicad_pcb]
2026-09-21 Move bottom silkscreen inside board edge
    [compute-blade-dda-adapter.kicad_pcb]
2026-09-21 Add upright DDA mechanical revision
    [compute-blade-dda-adapter.kicad_pcb, compute-blade-dda-adapter.kicad_sch, dda_simple_default.stl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]
2026-09-21 Clear DRC routing and silkscreen violations
    [compute-blade-dda-adapter.kicad_pcb]
2026-09-21 Clean connector silkscreen clearances
    [compute-blade-dda-adapter.kicad_pcb]
2026-09-21 Validate measured connector stack and DDA orientation
    [dda_simple_default.stl, dda_simple_rot180.stl]
2026-09-21 Require 3.4 mm DDA connector engagement
    [dda_simple_default.stl, dda_simple_rot180.stl]
2026-09-21 Generate inspectable full mechanical assembly
2026-09-21 Correct DDA rotation toward SSD side
    [compute-blade-dda-adapter.kicad_pcb, dda_simple_default.stl, dda_simple_rot180.stl]
2026-09-21 Expose KiCad DRC failures in CI annotations
2026-09-21 Use KiCad-correct J2 rotation convention
    [compute-blade-dda-adapter.kicad_pcb]
2026-09-21 Derive DDA assembly from physical axes
2026-09-21 Fix blank mechanical previews
    [generate_assembly_model.py, verify_render_outputs.py]
2026-09-21 Move upright DDA assembly to positive Y
    [compute-blade-dda-adapter.kicad_pcb, dda_simple_default.stl, dda_simple_rot180.stl]
2026-09-21 Add clearance-safe connector escape routing
    [compute-blade-dda-adapter.kicad_pcb]
2026-09-21 Preserve connector pad escapes during routing
    [compute-blade-dda-adapter.kicad_pcb]
2026-09-21 Route 5V pass-through along board perimeter
    [compute-blade-dda-adapter.kicad_pcb]
2026-09-22 Redesign adapter for parallel DDA stack
    [BOM.csv, compute-blade-dda-adapter.kicad_pcb, compute-blade-dda-adapter.kicad_sch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]
2026-09-22 Regenerate compact parallel assembly diagram
2026-09-22 Enforce routed segment clearances
    [compute-blade-dda-adapter.kicad_pcb]
2026-09-22 Respect square pin-one pad clearances
    [compute-blade-dda-adapter.kicad_pcb]
2026-09-22 Use conventional J2 on 1.0 mm adapter
    [BOM.csv, compute-blade-dda-adapter.kicad_pcb, compute-blade-dda-adapter.kicad_sch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]
2026-09-22 Add intentional J1 seating clearance
    [dda_simple_default.stl, j1_hle_105_02_l_dv_pe_be.step, j2_mtlw_106_05_g_d_140.step]
